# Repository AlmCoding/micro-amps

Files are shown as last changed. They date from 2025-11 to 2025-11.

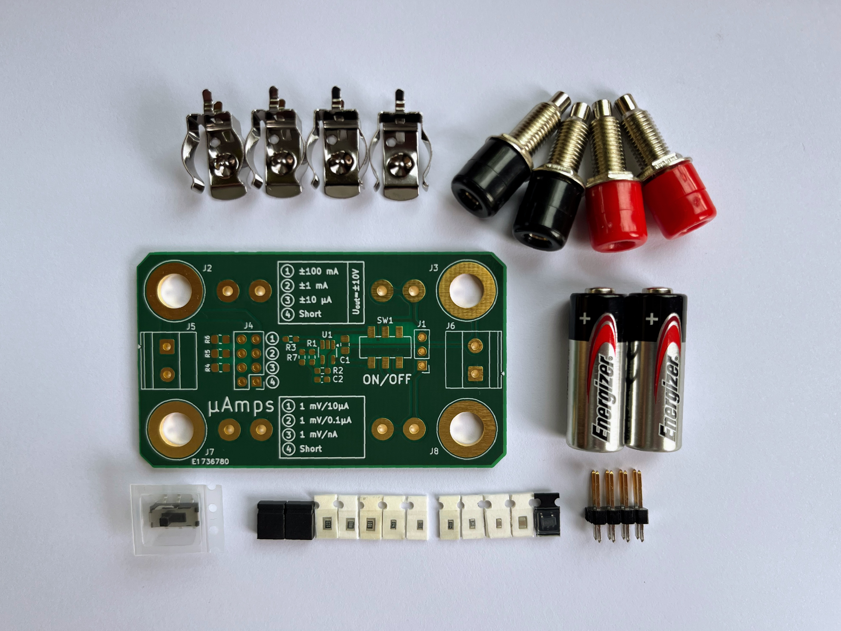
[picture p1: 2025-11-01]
images/components.jpg

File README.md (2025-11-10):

# 🔬 µAmps – Open-Hardware Current-to-Voltage Converter

**µAmps** is an open-hardware current-to-voltage converter designed as a practical, low-cost alternative to the µCurrent GOLD. It allows precise conversion of extremely small currents into a measurable voltage across three optimized ranges, making it ideal for low-power electronics and embedded device development.

With its analog voltage output, µAmps can be easily connected to a multimeter, oscilloscope, or data acquisition system, enabling engineers and makers to debug and verify power consumption down to the nanoamp level.

[Buy on Tindie](INSERT_TINDIE_LINK_HERE)

## 🧾 Technical Specifications

- **Current Ranges:**
  - ±120 mA @ 1 Ω shunt ➜ 1 mV/10 µA  
  - ±1.2 mA @ 100 Ω shunt ➜ 1 mV/0.1 µA  
  - ±12 µA @ 10 kΩ shunt ➜ 1 mV/nA
- **Output Voltage Range:** ±12 V
- **Output Offset Voltage:** <10 µV (@25°C)
- **Bandwidth:** >70 kHz (-3 dB)
- **Accuracy (typical):**
  - ±0.05% on µA and nA ranges  
  - ±1% on mA range
- **Battery:** 2x A23 (±12V)

## 🎯 Perfect For

- Measuring sleep currents of microcontrollers and low-power devices  
- Validating energy-saving or standby modes  
- Debugging ultra-low power electronics  
- Educational and experimental applications

The analog output allows direct measurement with standard lab equipment, providing a simple and effective way to monitor tiny currents in real-time.

## 🛠️ Open Hardware Files

All design files are open and available for use under the **CERN OHL v2** license:

- PCB design files (KiCad 9.0)  
- Schematic diagrams  
- Bill of Materials (BOM)  

Contributions, improvements, and forks are welcome. Please respect the original licensing terms.

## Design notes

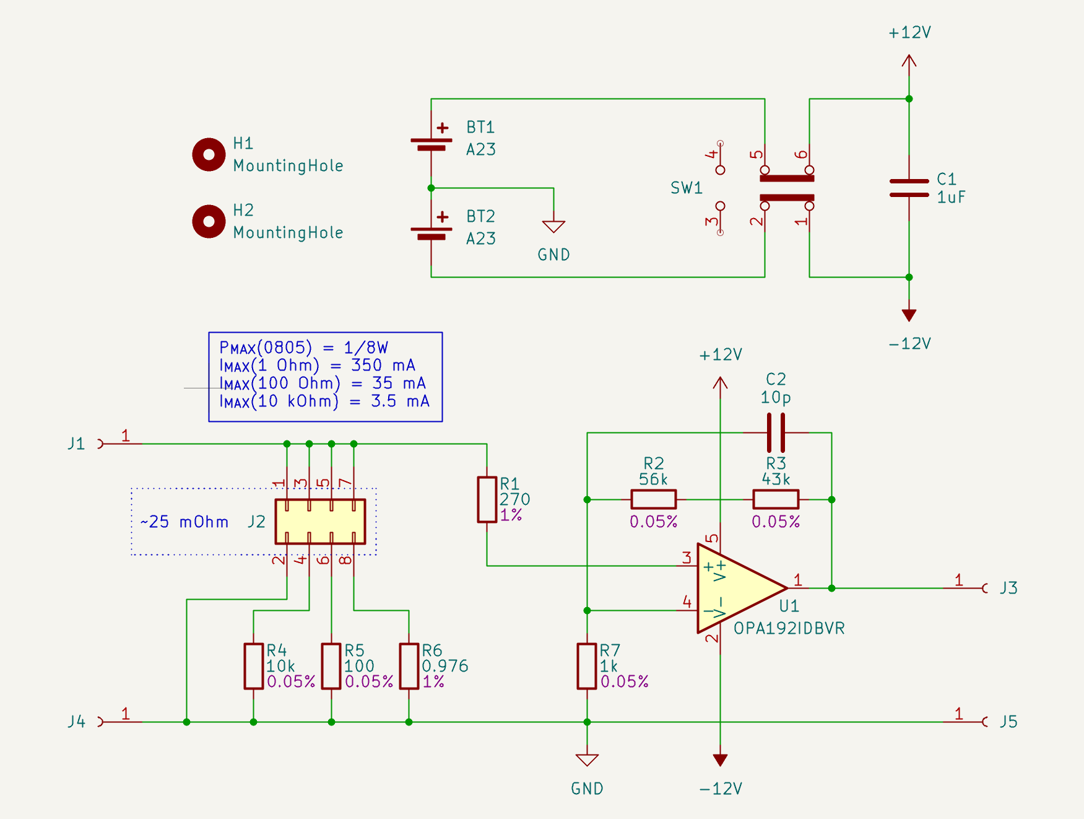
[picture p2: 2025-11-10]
images/schematic.png

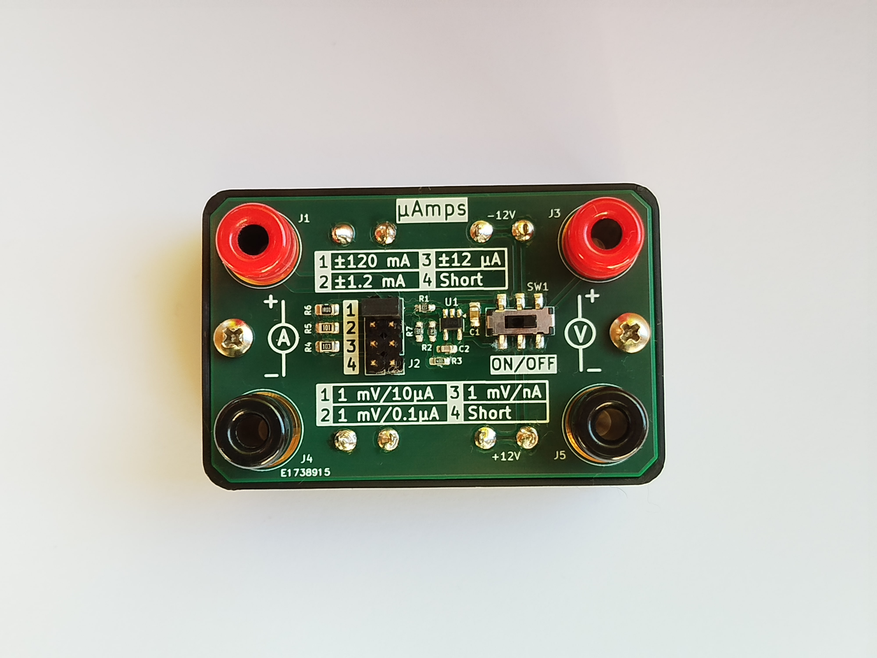
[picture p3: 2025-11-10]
images/front-min.jpg

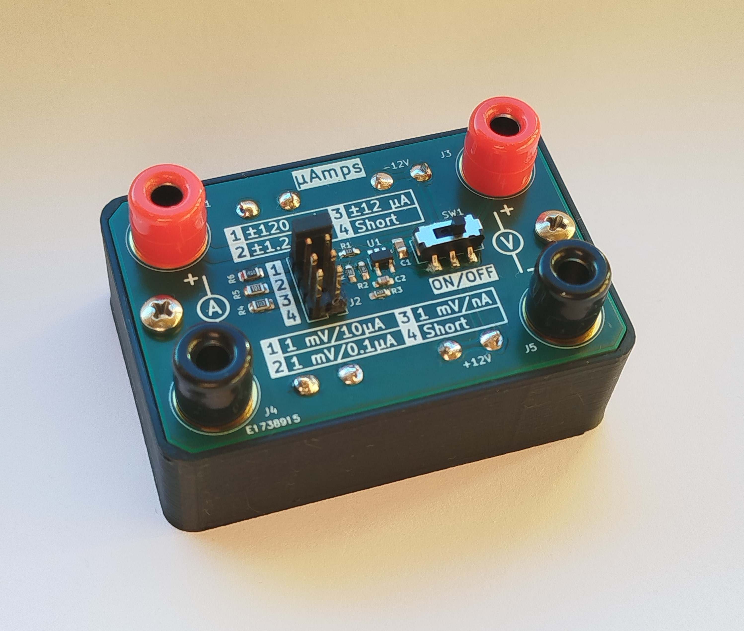
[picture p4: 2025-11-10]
images/front_angle_crop-min.jpg

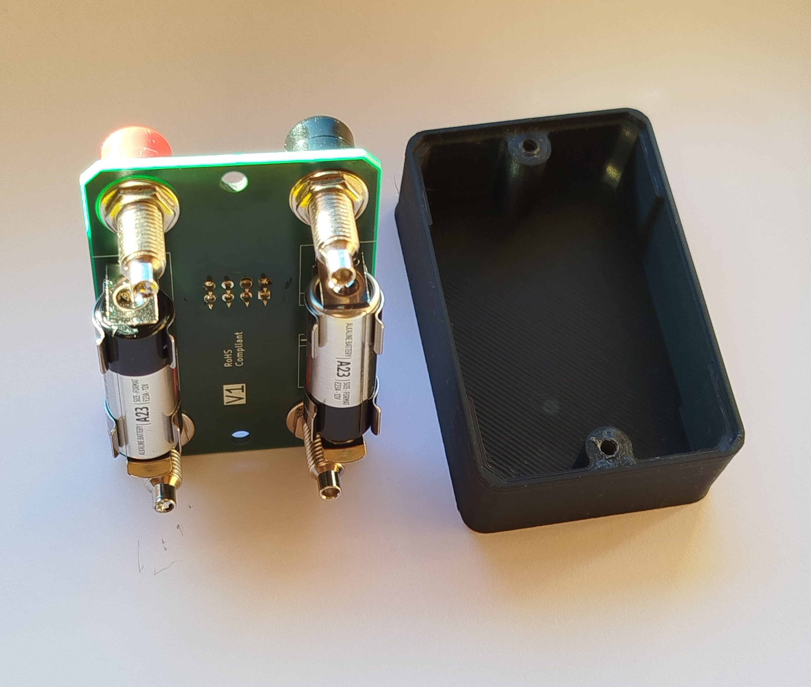
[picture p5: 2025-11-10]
images/back_open_crop-min.jpg

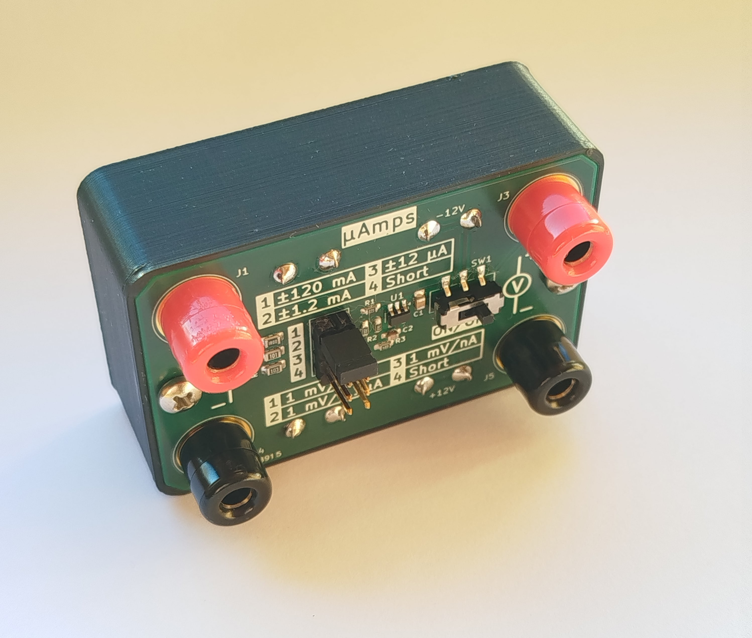
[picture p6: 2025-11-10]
images/side_angle_crop-min.jpg

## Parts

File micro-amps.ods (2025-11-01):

Id | Designator | Footprint | Quantity | Designation | Price (1 piece) | Price (€)
1 | R6 | R_0805_2012Metric_Pad1.20x1.40mm_HandSolder | 1 | 1 | 0.2 | 0.2
2 | R5 | R_0805_2012Metric_Pad1.20x1.40mm_HandSolder | 1 | 100 | 0.45 | 0.45
3 | R4 | R_0805_2012Metric_Pad1.20x1.40mm_HandSolder | 1 | 10k | 0.35 | 0.35
4 | BT2,BT1 | A23_Battery_Holder_Keystone_82 | 2 | A23 | 0.4 | 0.8
5 | J2,J3,J7,J8 | Banana_Jack_1Pin | 4 | Conn_01x01_Socket | 0.4 | 1.6
6 | C1 | C_0805_2012Metric_Pad1.18x1.45mm_HandSolder | 1 | 1uF | 0.1 | 0.1
7 | J1 | PinHeader_1x03_P2.54mm_Vertical | 1 | Conn_01x03_Pin
8 | SW1 | SW_DPDT_SLW_913535 | 1 | SW_Slide_DPDT | 0.45 | 0.45
9 | R1 | R_0603_1608Metric_Pad0.98x0.95mm_HandSolder | 1 | 56k | 0.32 | 0.32
10 | J5,J6 | TerminalBlock_MetzConnect_Type011_RT05502HBLC_1x02_P5.00mm_Horizontal | 2 | Screw_Terminal_01x02
11 | U1 | SOT-23-5_HandSoldering | 1 | OPA197xDBV | 2.2 | 2.2
12 | J4 | PinHeader_2x04_P2.54mm_Vertical | 1 | Conn_02x04_Odd_Even | 0.2 | 0.2
13 | R2 | R_0603_1608Metric_Pad0.98x0.95mm_HandSolder | 1 | 43k | 0.32 | 0.32
14 | C2 | C_0603_1608Metric_Pad1.08x0.95mm_HandSolder | 1 | 10p | 0.1 | 0.1
15 | R3 | R_0603_1608Metric_Pad0.98x0.95mm_HandSolder | 1 | 270 | 0.1 | 0.1
16 | R7 | R_0603_1608Metric_Pad0.98x0.95mm_HandSolder | 1 | 1k | 0.32 | 0.32
 |  |  |  |  | PCB | 6
 |  |  |  |  | SUM | 13.51
 |  |  |  |  | with VAT | 16.212
 |  |  |  |  |  |  | 20 euro for set
 |  |  |  |  |  |  | 30 euro assembled
 |  |  |  |  |  |  | 5 euro for 3D case?

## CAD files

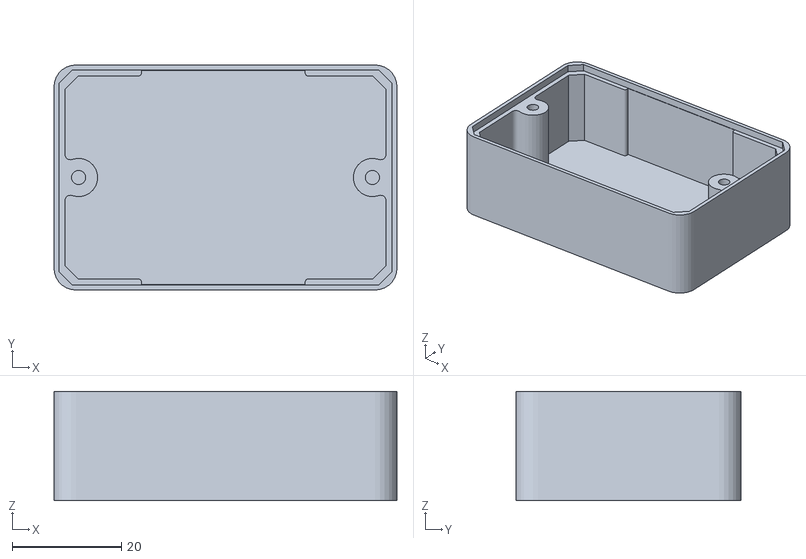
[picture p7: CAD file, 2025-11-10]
case/case-Body.stl
62.8 x 41.2 x 20.0

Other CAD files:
case/case.FCStd

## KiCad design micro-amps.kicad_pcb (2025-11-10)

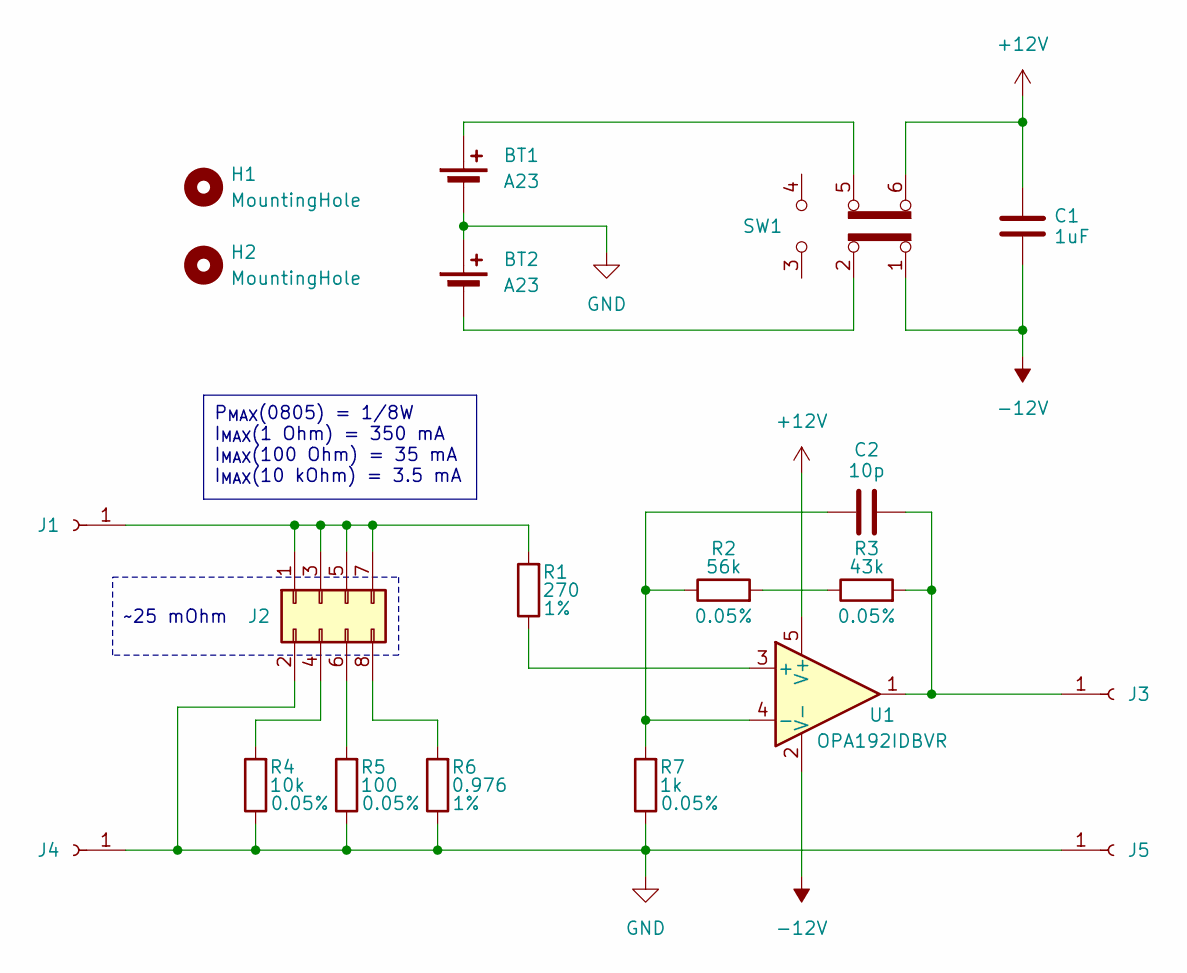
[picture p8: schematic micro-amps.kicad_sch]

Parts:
BT1, BT2: A23; A23_Battery_Holder_Keystone_82
C1: 1uF; C_0805_2012Metric_Pad1.18x1.45mm_HandSolder
C2: 10p; C_0603_1608Metric_Pad1.08x0.95mm_HandSolder
H1, H2: MountingHole; MountingHole_3.2mm_M3
J1, J3, J4, J5: Conn_01x01_Socket; Banana_Jack_1Pin
J2: Conn_02x04_Odd_Even; PinHeader_2x04_P2.54mm_Vertical
R1: 270; R_0603_1608Metric_Pad0.98x0.95mm_HandSolder; Tolerance 1%
R2: 56k; R_0603_1608Metric_Pad0.98x0.95mm_HandSolder; Tolerance 0.05%
R3: 43k; R_0603_1608Metric_Pad0.98x0.95mm_HandSolder; Tolerance 0.05%
R4: 10k; R_0805_2012Metric_Pad1.20x1.40mm_HandSolder; Tolerance 0.05%
R5: 100; R_0805_2012Metric_Pad1.20x1.40mm_HandSolder; Tolerance 0.05%
R6: 0.976; R_0805_2012Metric_Pad1.20x1.40mm_HandSolder; Tolerance 1%
R7: 1k; R_0603_1608Metric_Pad0.98x0.95mm_HandSolder; Tolerance 0.05%
SW1: SW_Slide_DPDT; SW_DPDT_SLW_913535
U1: OPA192IDBVR; SOT-23-5_HandSoldering

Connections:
+12V: C1.1, SW1.6 (C), U1.5 (V+)
-12V: C1.2, SW1.1 (A), U1.2 (V-)
GND: BT1.2 (-), BT2.1 (+), J2.2, J4.1, J5.1, R4.1, R5.1, R6.1, R7.1
unnamed: BT1.1 (+), SW1.5 (B)
unnamed: BT2.2 (-), SW1.2 (B)
unnamed: J1.1, J2.1, J2.3, J2.5, J2.7, R1.2
unnamed: J2.4, R4.2
unnamed: J2.6, R5.2
unnamed: J2.8, R6.2
unnamed: C2.1, J3.1, R3.2, U1.1
unnamed: R2.2, R3.1
unnamed: R1.1, U1.3 (+)
unnamed: C2.2, R2.1, R7.2, U1.4 (-)

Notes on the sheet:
~25 mOhm
P_{MAX}(0805) = 1/8W I_{MAX}(1 Ohm) = 350 mA I_{MAX}(100 Ohm) = 35 mA I_{MAX}(10 kOhm) = 3.5 mA

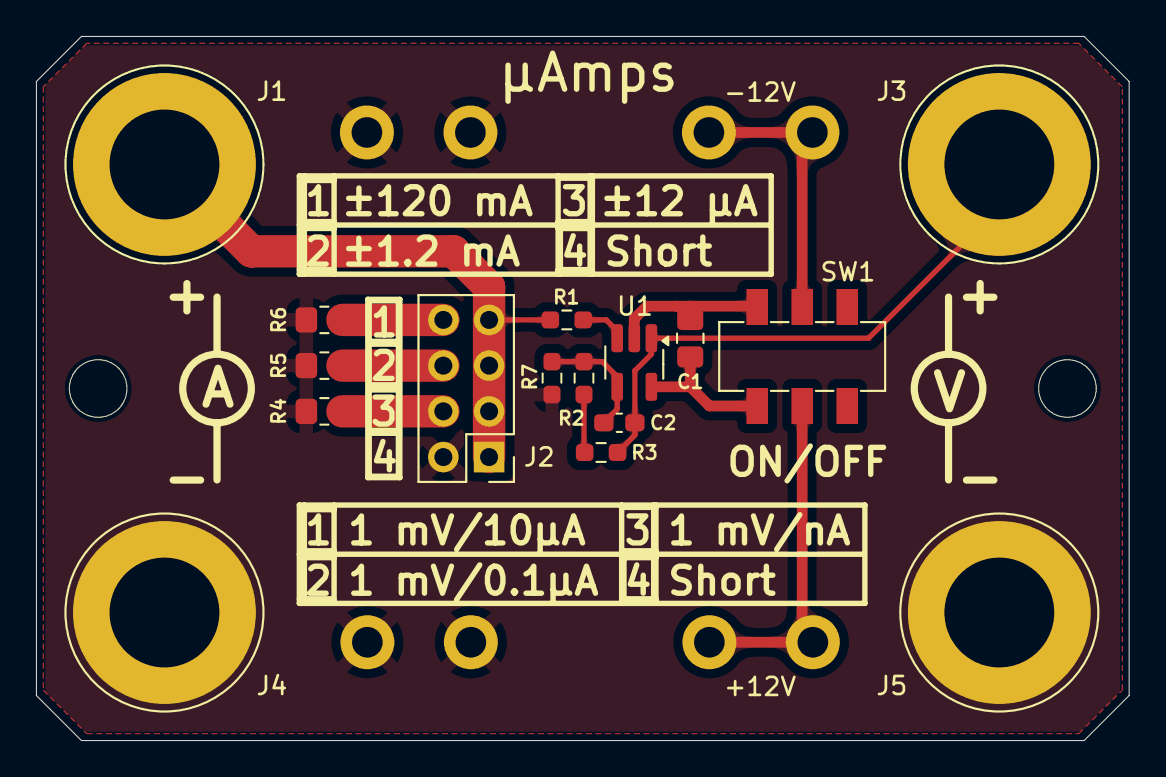
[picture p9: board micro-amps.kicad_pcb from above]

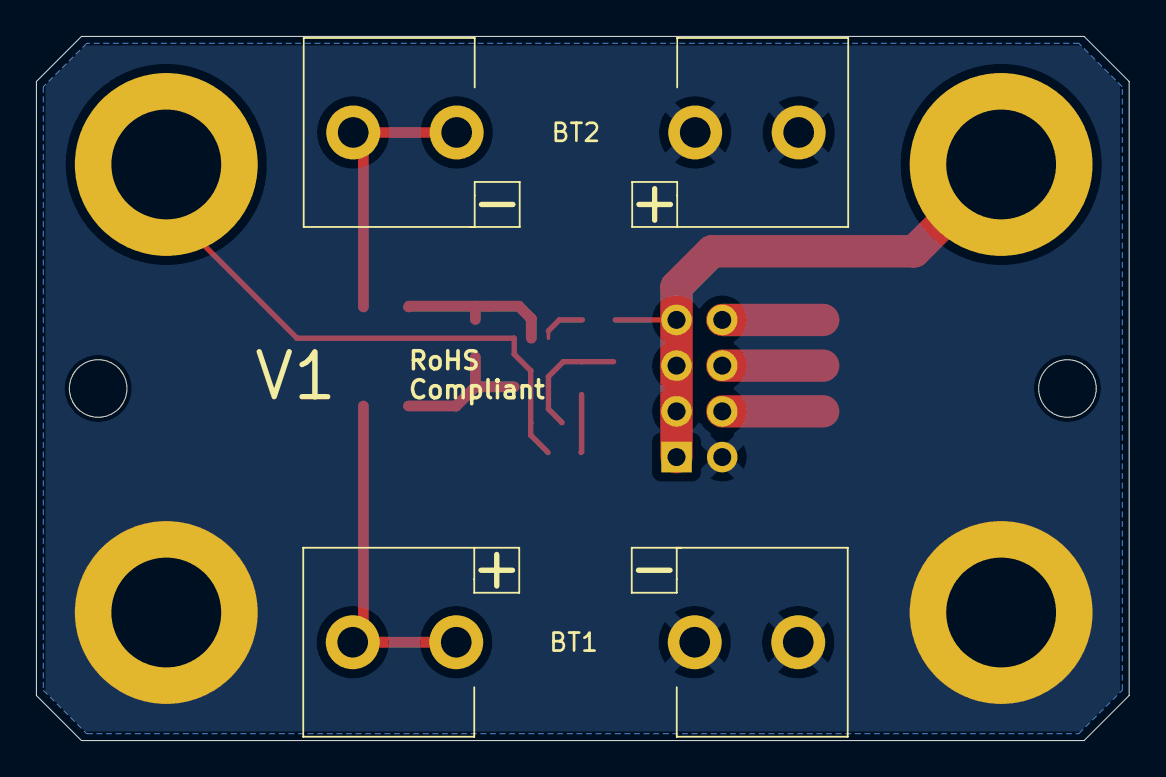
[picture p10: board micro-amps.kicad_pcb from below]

Board: 2 copper layers, 60.7 x 39.1 mm, 20 parts (2 on the bottom side), 13 nets.

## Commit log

2025-11-01 Single OPAMP stage
    [micro-amps.kicad_pcb, micro-amps.kicad_sch, micro-amps.ods]
2025-11-02 Optimize layout
    [micro-amps.kicad_pcb, micro-amps.kicad_sch]
2025-11-10 Refine things
    [case-Body.stl, case.FCStd, micro-amps.kicad_pcb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]
